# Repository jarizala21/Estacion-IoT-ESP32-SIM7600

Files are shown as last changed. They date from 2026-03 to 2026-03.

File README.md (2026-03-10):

# Estación IoT de Monitorización de Temperatura

Proyecto de estación autónoma basada en **ESP32 + SIM7600** que mide temperatura y envía los datos a **Google Sheets mediante LTE**.

El sistema está diseñado para funcionar durante largos periodos con **baterías 18650** utilizando **deep sleep**.

---

# Hardware

Elementos principales utilizados:

- ESP32
- Módulo LTE **SIM7600**
- Sensor **PT100** con **MAX31865**
- Sensor **LM35** (temperatura interna)
- Baterías **18650**
- Circuito de carga **MCP73871**
- Load switch **TPS22918**
- PCB diseñada en **KiCad**

---

# Funcionamiento

El sistema funciona de la siguiente manera:

1. El ESP32 se despierta desde **deep sleep**
2. Enciende el **SIM7600**
3. Se conecta a la red LTE
4. Sincroniza la hora mediante **NTP**
5. Lee los sensores
6. Envía los datos a **Google Sheets**
7. Apaga el módem
8. Vuelve a **deep sleep**

Actualmente el sistema envía datos a:

- **08:45**
- **13:00**

---

# Firmware

El firmware está desarrollado en **C++ usando PlatformIO**.

Características:

- Comunicación LTE mediante comandos AT
- Sincronización de hora con NTP
- Lectura de sensores
- Envío HTTP a Google Sheets
- Gestión de batería
- Deep sleep

El código se encuentra en:

Firmware/EstacionIot/src/main.cpp

---

# Esquema eléctrico

El esquema del sistema se puede consultar aquí:

[Esquema del sistema](Hardware/Proyecto/Esquema_V1.pdf)

---

# PCB

La PCB fue diseñada con **KiCad**.

Los archivos del proyecto se encuentran en:

Hardware/Proyecto

---

# Autor

Proyecto desarrollado por:

**Jonathan Arizala**

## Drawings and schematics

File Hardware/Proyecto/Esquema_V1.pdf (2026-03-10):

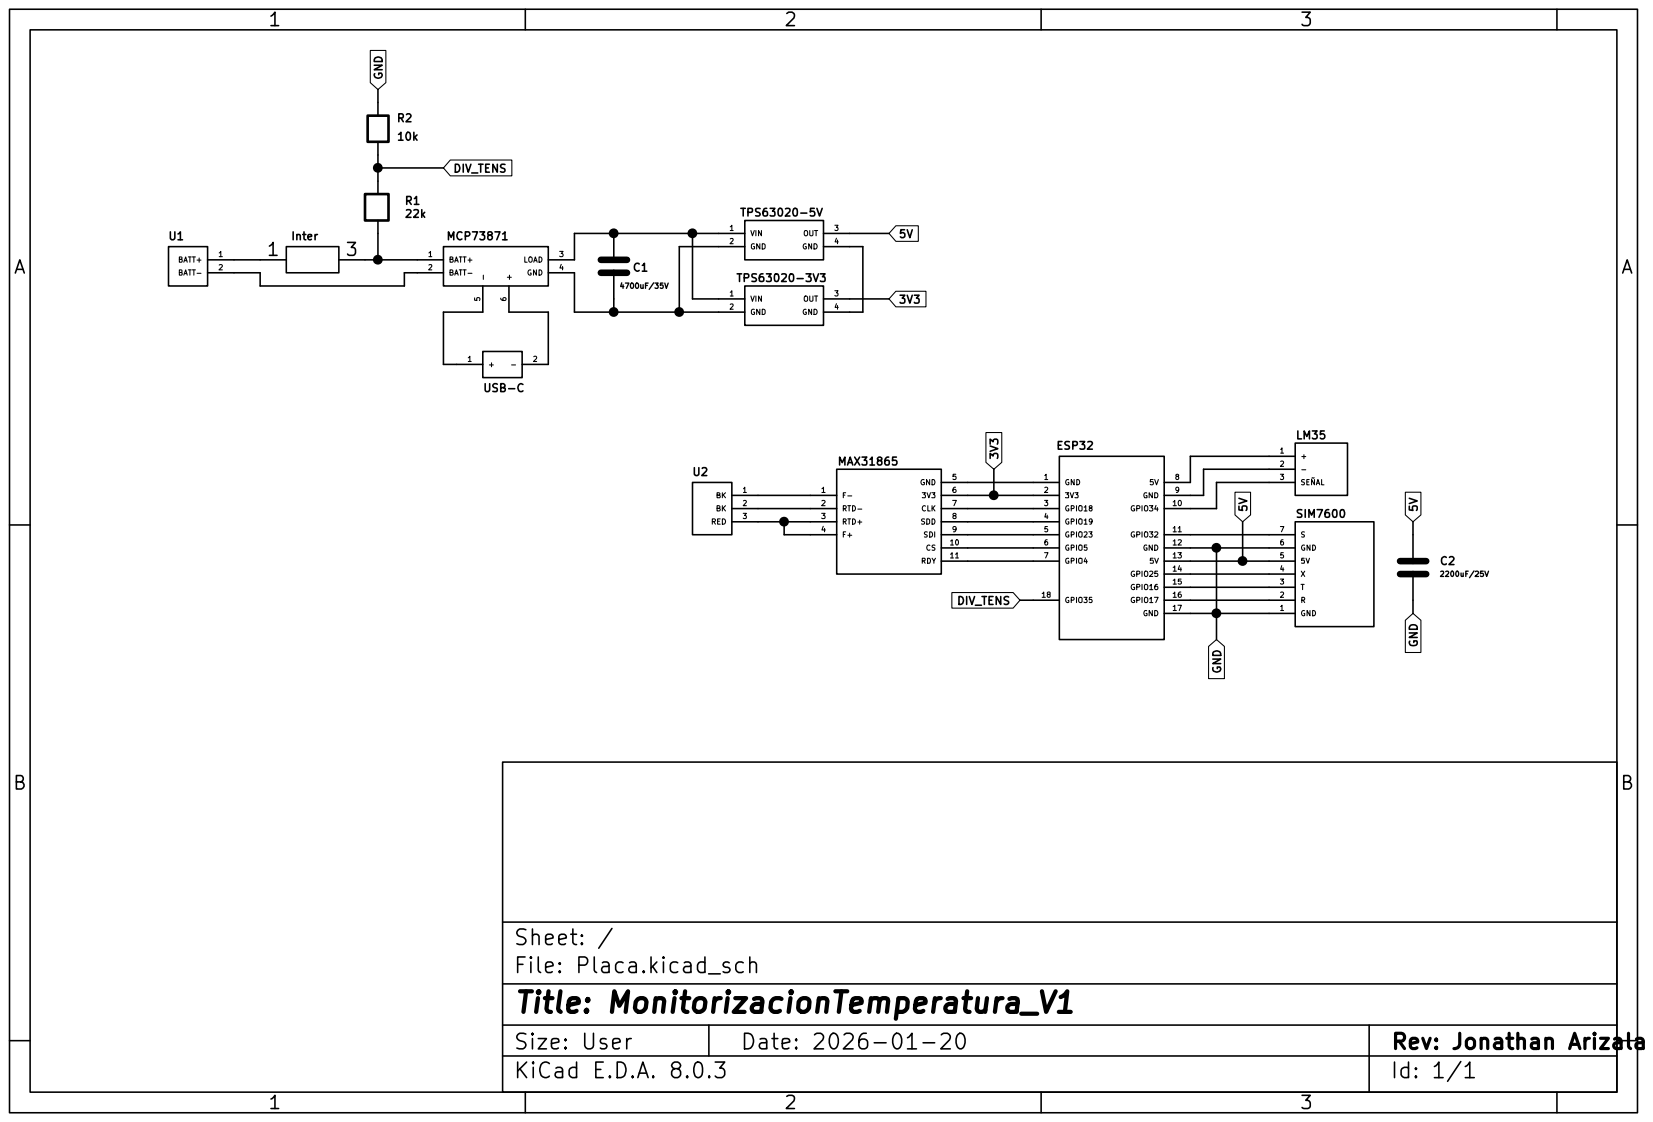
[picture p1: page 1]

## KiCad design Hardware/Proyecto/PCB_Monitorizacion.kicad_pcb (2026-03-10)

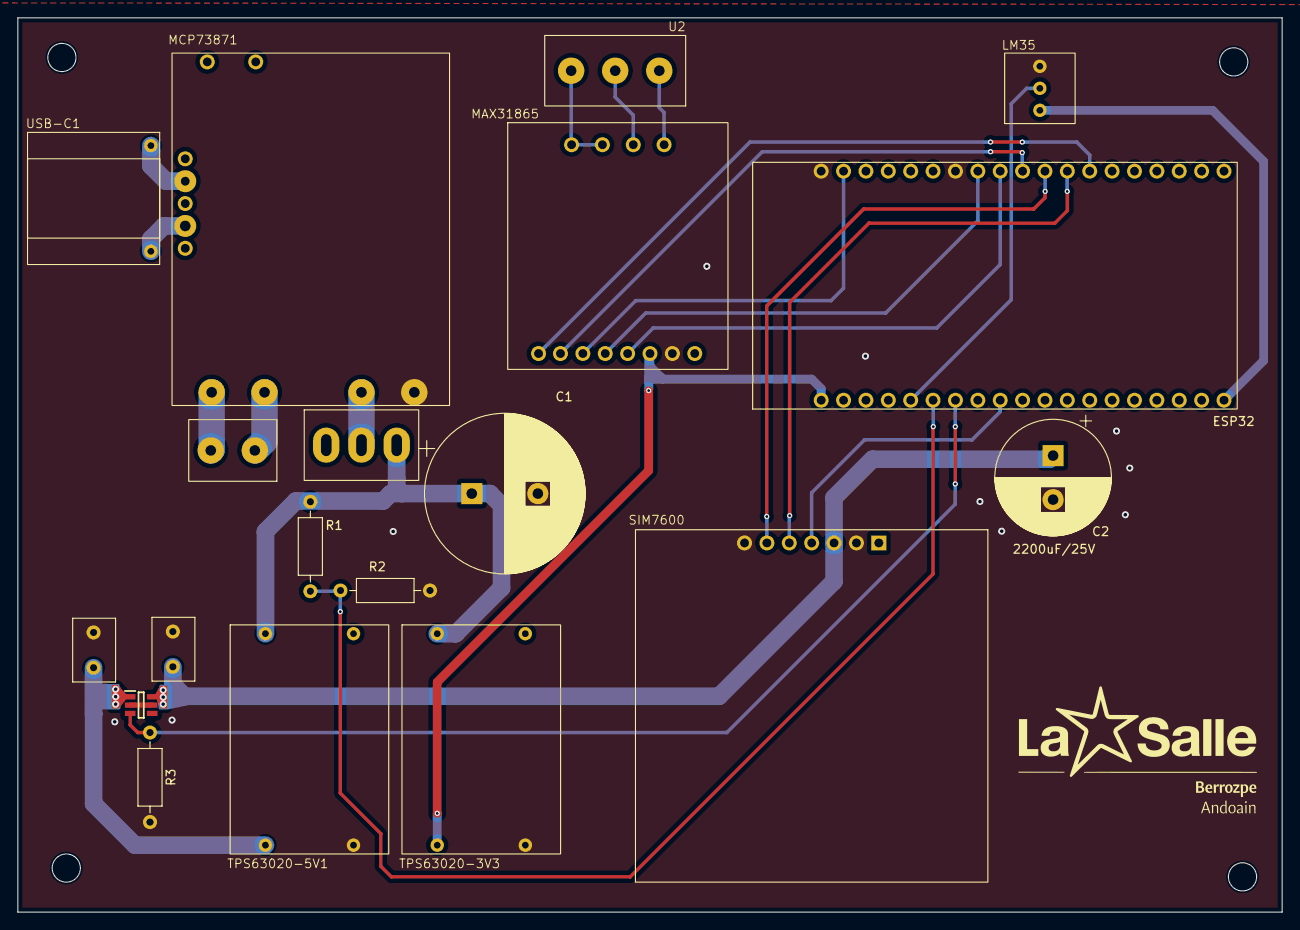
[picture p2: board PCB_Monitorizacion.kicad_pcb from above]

Board: 2 copper layers, 143.5 x 101.5 mm, 19 parts (0 on the bottom side), 26 nets.

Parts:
C1: 4700uF/35V; CP_Radial_D18.0mm_P7.50mm
C2: 2200uF/25V; CP_Radial_D13.0mm_P5.00mm
C3, C4: 1uF/63V; Cap_7.5mm_5mm
ESP32: ESP32
IC1: TPS22918TDBVTQ1; SOT95P280X145-6N
Inter1: Interruptor3Pines
LM35: LM35
MAX31865: MAX31865
MCP73871: MCP73871
R1: 22k; R_Axial_DIN0207_L6.3mm_D2.5mm_P10.16mm_Horizontal
R2: 10k; R_Axial_DIN0207_L6.3mm_D2.5mm_P10.16mm_Horizontal
R3: 100k; R_Axial_DIN0207_L6.3mm_D2.5mm_P10.16mm_Horizontal
SIM7600: SIM7600
TPS63020-3V3, TPS63020-5V1: TPS63020
U1: Conn5mm_02x01
U2: Conn5mm_03x01
USB-C1: USB-C

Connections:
3V3: ESP32.2 (3V3), MAX31865.6 (3V3), TPS63020-3V3.3 (OUT)
5V: C3.2, IC1.1 (VIN), TPS63020-5V1.3 (OUT)
DIV_TENS: ESP32.18 (GPIO35), R1.1, R2.2
GND: C1.2, C2.2, C3.1, C4.1, ESP32.1 (GND), ESP32.9 (GND), IC1.2 (GND), IC1.5 (QOD), LM35.2 (-), MAX31865.5 (GND), MCP73871.4 (GND), R2.1, R3.2, SIM7600.1 (GND), SIM7600.6 (GND), TPS63020-3V3.4 (GND), TPS63020-5V1.4 (GND)
unnamed: ESP32.8 (5V), LM35.1 (+)
unnamed: ESP32.7 (GPIO4), MAX31865.11 (RDY)
unnamed: ESP32.6 (GPIO5), MAX31865.10 (CS)
unnamed: ESP32.15 (GPIO16), SIM7600.3 (T)
unnamed: ESP32.16 (GPIO17), SIM7600.2 (R)
unnamed: ESP32.3 (GPIO18), MAX31865.7 (CLK)
unnamed: ESP32.4 (GPIO19), MAX31865.8 (SDD)
unnamed: ESP32.5 (GPIO23), MAX31865.9 (SDI)
unnamed: ESP32.14 (GPIO25), SIM7600.4 (X)
unnamed: ESP32.10 (GPIO34), LM35.3 (SEÑAL)
unnamed: MAX31865.3 (RTD+), MAX31865.4 (F+), U2.3 (RED)
unnamed: MAX31865.1 (F-), U2.1 (BK)
unnamed: MAX31865.2 (RTD-), U2.2 (BK)
unnamed: MCP73871.6 (+), USB-C1.1 (+)
unnamed: MCP73871.5 (-), USB-C1.2 (-)
unnamed: MCP73871.1 (BATT+), U1.1 (BATT+)
unnamed: MCP73871.2 (BATT-), U1.2 (BATT-)
unnamed: TPS63020-3V3.2 (GND), TPS63020-5V1.2 (GND)
unnamed: Inter1.1, MCP73871.3 (LOAD)
unnamed: C1.1, Inter1.3, R1.2, TPS63020-3V3.1 (VIN), TPS63020-5V1.1 (VIN)
ON: ESP32.11 (GPIO32), IC1.3 (ON), R3.1
VOUT: C2.1, C4.2, IC1.6 (VOUT), SIM7600.5 (5V)

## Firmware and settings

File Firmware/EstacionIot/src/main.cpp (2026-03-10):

#include <Arduino.h>
#include <SPI.h>
#include <esp_sleep.h>
#include <Adafruit_MAX31865.h>
#include "config.h"   // Archivo con datos privados

#define LOADSW_PIN 32
#define SIM_RX      16
#define SIM_TX      17
#define SIM_PWRKEY  25
#define SIM_BAUD    115200

HardwareSerial sim7600(2);

#define BAT_PIN 35
#define R1 22.0
#define R2 10.0
#define BAT_SAMPLES 8

#define MAX_CS   5
#define MAX_DI   23
#define MAX_DO   19
#define MAX_CLK  18
#define RNOMINAL 100.0
#define RREF     423.0

Adafruit_MAX31865 max31865(MAX_CS, MAX_DI, MAX_DO, MAX_CLK);

void sendAT(const char* cmd, uint32_t waitMs = 1000) {
  sim7600.println(cmd);
  delay(waitMs);
}

String readSIMResponse(uint32_t timeoutMs = 2000) {
  String resp = "";
  uint32_t t = millis();
  while (millis() - t < timeoutMs) {
    while (sim7600.available()) resp += (char)sim7600.read();
    if (resp.indexOf("OK") != -1 || resp.indexOf("ERROR") != -1) break;
    delay(10);
  }
  return resp;
}

bool getCCLKFull(int &hour, int &minute, int &second) {
  while (sim7600.available()) sim7600.read();
  sim7600.println("AT+CCLK?");
  String resp = readSIMResponse(3000);
  int q1 = resp.indexOf('"');
  int q2 = resp.lastIndexOf('"');
  if (q1 == -1 || q2 == -1 || q1 == q2) return false;

  String raw = resp.substring(q1 + 1, q2);
  int comma = raw.indexOf(',');
  if (comma == -1) return false;

  String timePart = raw.substring(comma + 1);

  hour   = timePart.substring(0, 2).toInt() - 1;
  if (hour < 0) hour += 24;

  minute = timePart.substring(3, 5).toInt();
  second = timePart.substring(6, 8).toInt();

  return true;
}

void powerOnSIM7600() {
  digitalWrite(SIM_PWRKEY, LOW);
  delay(1500);
  digitalWrite(SIM_PWRKEY, HIGH);
}

void powerOffSIM7600() {
  sendAT("AT+CPOWD=1", 5000);
  digitalWrite(SIM_PWRKEY, LOW);
  delay(3000);
  digitalWrite(SIM_PWRKEY, HIGH);
}

float readBat() {
  uint32_t mv_sum = 0;
  for (int i = 0; i < BAT_SAMPLES; i++) {
    mv_sum += analogReadMilliVolts(BAT_PIN);
    delay(5);
  }
  return (mv_sum / (float)BAT_SAMPLES / 1000.0) * ((R1 + R2) / R2);
}

void sendData(float tempExt, float tempInt, float vBat) {

  String url = String(BASE_URL);
  url += "?temp="    + String(tempExt, 2);
  url += "&tempint=" + String(tempInt, 2);
  url += "&bat="     + String(vBat, 3);

  sendAT("AT+HTTPTERM");
  sendAT("AT+HTTPINIT");
  sendAT("AT+HTTPPARA=\"CID\",1");

  sim7600.print("AT+HTTPPARA=\"URL\",\"");
  sim7600.print(url);
  sim7600.println("\"");
  delay(1000);

  sendAT("AT+HTTPACTION=0", 10000);
}

uint64_t secondsUntil(int curH, int curM, int curS, int tH, int tM) {
  int totalNow    = curH * 3600 + curM * 60 + curS;
  int totalTarget = tH  * 3600 + tM  * 60;

  if (totalTarget <= totalNow) totalTarget += 24 * 3600;

  return (uint64_t)(totalTarget - totalNow);
}

void setup() {

  Serial.begin(115200);

  pinMode(LOADSW_PIN, OUTPUT);
  digitalWrite(LOADSW_PIN, HIGH);

  pinMode(SIM_PWRKEY, OUTPUT);
  digitalWrite(SIM_PWRKEY, HIGH);

  sim7600.begin(SIM_BAUD, SERIAL_8N1, SIM_RX, SIM_TX);

  analogReadResolution(12);
  analogSetAttenuation(ADC_11db);

  max31865.begin(MAX31865_2WIRE);

  delay(2000);

  powerOnSIM7600();
  delay(12000);

  sendAT("AT");
  sendAT("AT+CPIN?");
  sendAT("AT+CPIN=\"" SIM_PIN "\"", 8000);
  sendAT("AT+CREG?");
  sendAT("AT+CSOCKSETPN=1");
  sendAT("AT+NETOPEN", 6000);

  sendAT("AT+CGDCONT=1,\"IP\",\"" APN "\"");
  sendAT("AT+CGACT=1,1", 3000);

  sendAT("AT+CNTP=\"pool.ntp.org\",8");
  sendAT("AT+CNTP", 5000);

  int hour = 0, minute = 0, second = 0;
  getCCLKFull(hour, minute, second);

  bool sendNow = (hour == 8  && minute == 45) ||
                 (hour == 13 && minute == 0);

  if (sendNow) {

    float tempExt = max31865.temperature(RNOMINAL, RREF);
    float tempInt = analogReadMilliVolts(34) / 10.0;
    float vBat    = readBat();

    sendData(tempExt, tempInt, vBat);
  }

  uint64_t sTo845  = secondsUntil(hour, minute, second, 8, 45);
  uint64_t sTo1300 = secondsUntil(hour, minute, second, 13, 0);

  uint64_t sleepSec = (sTo845 < sTo1300) ? sTo845 : sTo1300;

  powerOffSIM7600();
  delay(5000);

  digitalWrite(LOADSW_PIN, LOW);
  delay(1000);

  esp_sleep_enable_timer_wakeup(sleepSec * 1000000ULL);
  esp_deep_sleep_start();
}

void loop() {}

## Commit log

2026-03-10 Primer commit del firmware estación IoT
    Añadido proyecto PlatformIO con estructura inicial y configuración.
    [config.h.txt]
2026-03-10 Primer commit del firmware estación IoT
    [config.h.txt]
2026-03-10 Primer commit del Hardware
    [PCB_Monitorizacion.kicad_pcb, PCB_Monitorizacion.kicad_sch]
